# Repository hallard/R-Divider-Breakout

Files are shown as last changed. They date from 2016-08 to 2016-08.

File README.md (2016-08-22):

Voltage divider breakout for 4 Channels ADS1015/ADS1115 ADC Board
=================================================================

This shield is used to decrease voltage input when it's higher than the embeded device can hold. For example with 3.3V devices we can't hold input W 3.3V and measuring for example Lipo Battery or Solar Panel voltage is not possible.
This board indroduce 
- 4 voltage divider 
- I2C ADS1x15 board compatible for devices that do not have enought ADC such as [WeMos][1]
- Footprint for 0805 caps for filtering input.

This board can fit on Adafruit [ADS1115][5] or [ADS1015][6] 
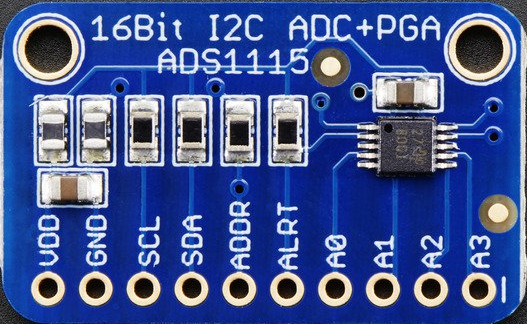
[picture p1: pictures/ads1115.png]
ADS1115


**In this case take care to just connect A0..A3 and GND to Adafruit board when stacking** other Adafruit board pins are used for input on my breakout.

**Waiting Boards from PCBs.io and OSHPark, I did not fully tested them yet, I will update ASAP. Use at your own risks**

Detailed Description
====================

Look at the schematics for more informations.

### Schematic
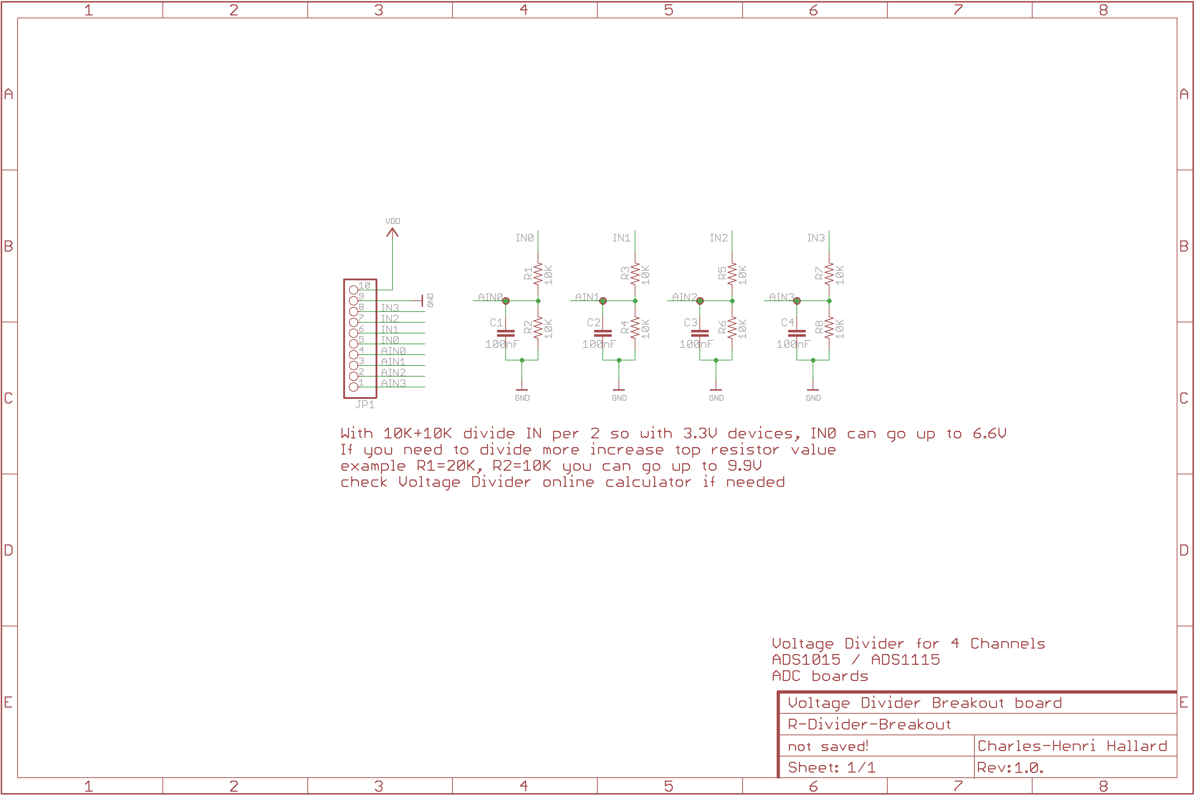
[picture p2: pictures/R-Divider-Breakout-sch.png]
schematic
  

### Boards 
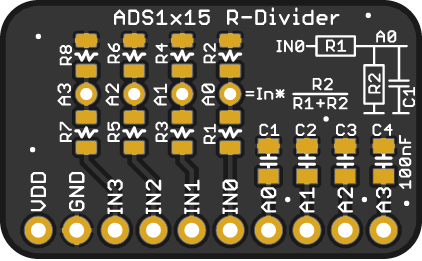
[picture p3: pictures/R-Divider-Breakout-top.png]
Top


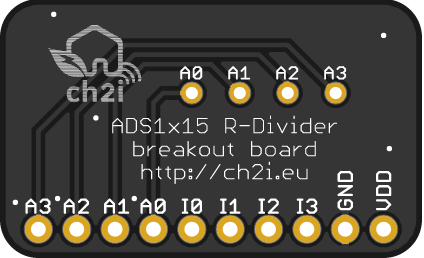
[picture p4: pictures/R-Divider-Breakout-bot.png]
Bottom
 

### Received boards

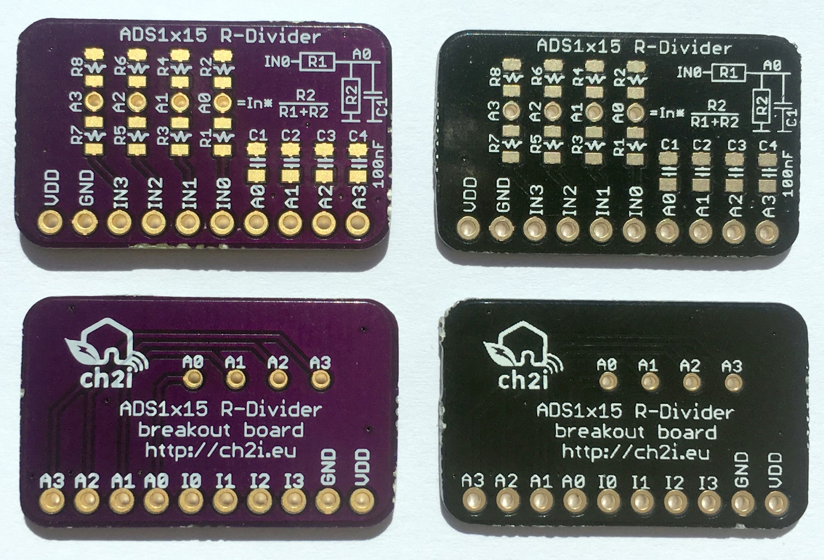
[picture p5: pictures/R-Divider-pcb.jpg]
PCB
 

You can order the PCB of this board at [OSHPARK][4] or at [PCBs.io][3].
PCBs.io give me some reward when you order my designed boards from their site. This is pretty cool because I can use these rewards to create and design new boards and order boards for a discounted price, so if you don't care about PCB manufacturer please use PCBs.io.

### Assembled boards

Here is a picture of assembled board stacked with an ADS1115 ADC breakout

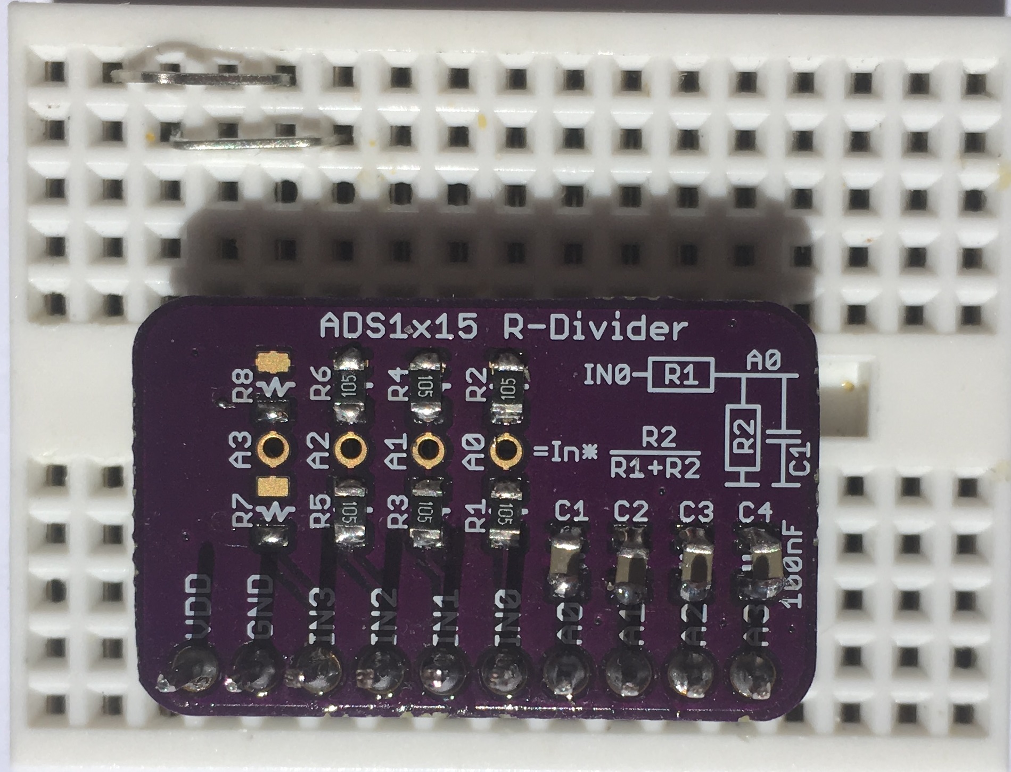
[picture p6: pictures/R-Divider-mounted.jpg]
Mounted boards
 

Take care when stacking, analog Input of breakout should not be connected to ADS1115 dedicated I2C and ADC control line, you'll need to use on long pin connector as follow

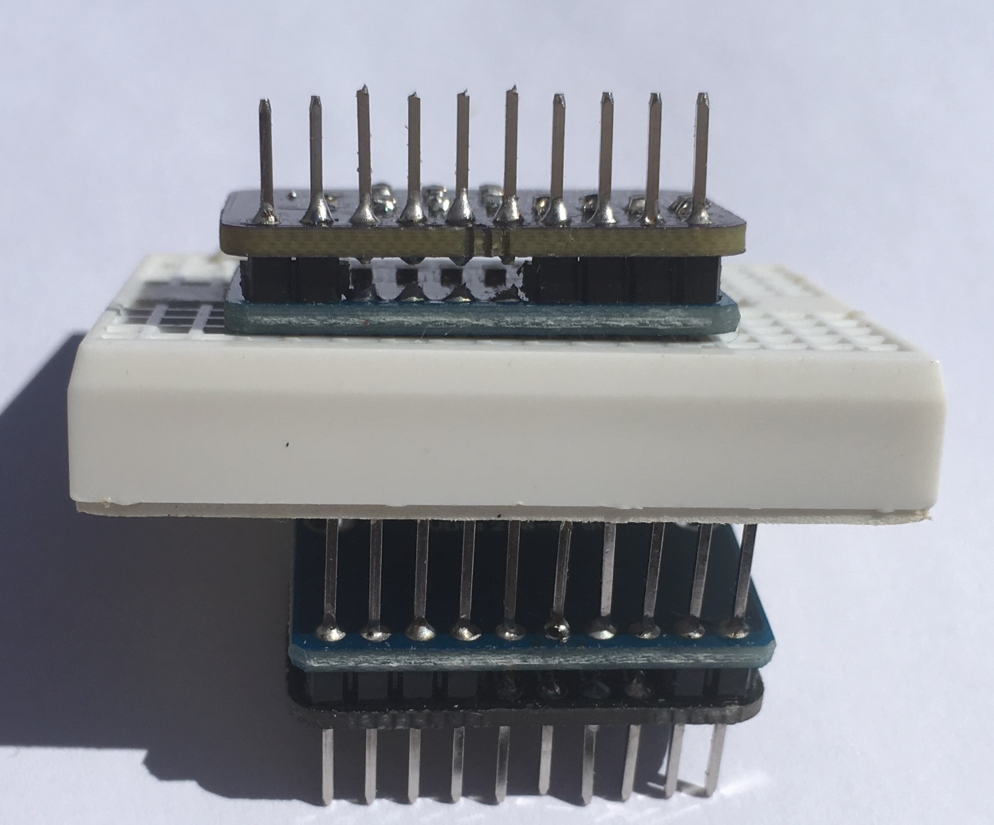
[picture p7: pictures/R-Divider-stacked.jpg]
Mounted and stacked with ADS1115 board
 

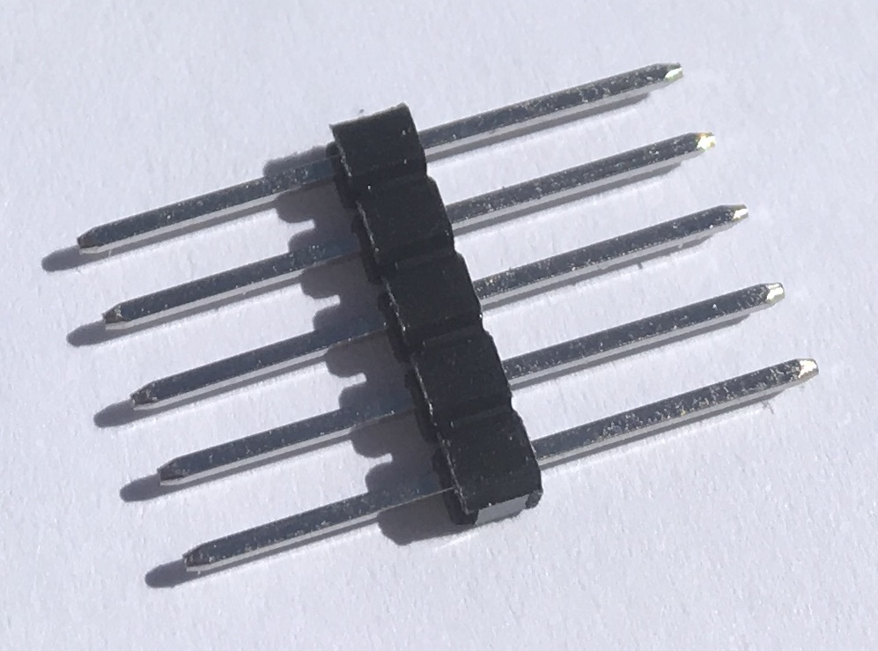
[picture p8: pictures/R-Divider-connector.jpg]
Long pin connector
 

##License

You can do whatever you like with this design.

##Misc
See news and other projects on my [blog][1] 
 
[1]: http://www.wemos.cc/Products/d1_mini.html
[2]: https://hallard.me
[3]: https://PCBs.io/share/rJ1B8 
[4]: https://oshpark.com/shared_projects/vyab8UWr
[5]: https://www.adafruit.com/product/1085
[6]: https://www.adafruit.com/products/1083

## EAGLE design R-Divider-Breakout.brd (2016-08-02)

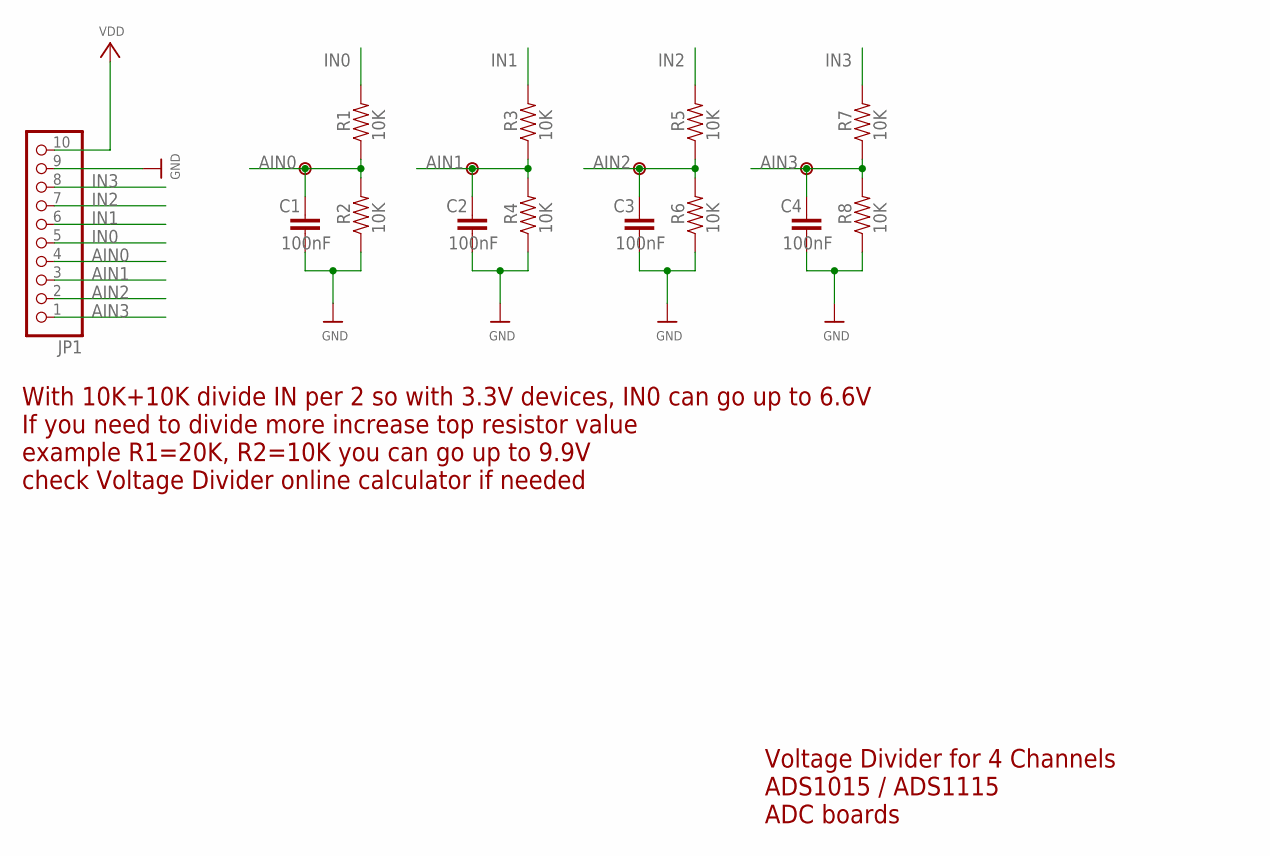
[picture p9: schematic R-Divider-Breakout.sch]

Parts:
C1, C2, C3, C4: 100nF; 0805-CAP
JP1: HEADER-1X1070MIL; 1X10_ROUND70
P1, P2, P3, P4: PADSMALL; PAD-SMALL
R1, R2, R3, R4, R5, R6, R7, R8: 10K; 0805-RES

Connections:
AIN0: C1.1, JP1.4, P1.1, R1.1, R2.2
AIN1: C2.1, JP1.3, P2.1, R3.1, R4.2
AIN2: C3.1, JP1.2, P3.1, R5.1, R6.2
AIN3: C4.1, JP1.1, P4.1, R7.1, R8.2
GND: C1.2, C2.2, C3.2, C4.2, JP1.9, R2.1, R4.1, R6.1, R8.1
IN0: JP1.5, R1.2
IN1: JP1.6, R3.2
IN2: JP1.7, R5.2
IN3: JP1.8, R7.2
VDD: JP1.10

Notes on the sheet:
Voltage Divider for 4 Channels ADS1015 / ADS1115 ADC boards
With 10K+10K divide IN per 2 so with 3.3V devices, IN0 can go up to 6.6V If you need to divide more increase top resistor value example R1=20K, R2=10K you can go up to 9.9V check Voltage Divider online calculator if needed

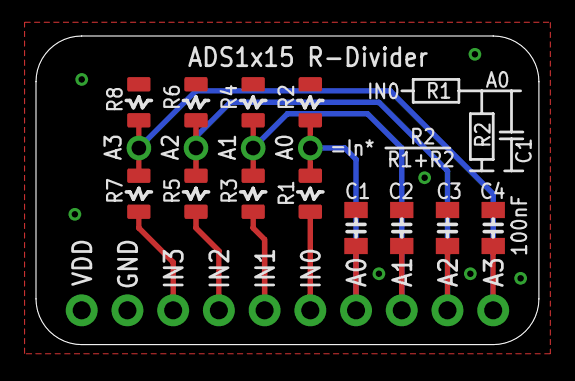
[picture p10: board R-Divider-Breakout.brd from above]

Board: 2 copper layers, 27.9 x 17.1 mm, 18 parts (1 on the bottom side), 9 nets.

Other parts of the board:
U$5: LOGO_C2I_015

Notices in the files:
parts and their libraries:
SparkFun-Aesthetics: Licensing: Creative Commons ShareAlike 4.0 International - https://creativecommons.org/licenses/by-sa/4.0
